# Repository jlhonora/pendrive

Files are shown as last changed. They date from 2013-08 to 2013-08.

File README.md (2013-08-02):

Build your own pendrive
=======================

This repo contains all the necessary material to build your own open-source pendrive, including the software source code, the design files and Gerber prints for the Printed Circuit Board and the 3D model of the plastic enclosure. Feel free to modify it as you like!

The microcontroller used is a TI msp430 of the F55xx family (msp430F5510 for now).

To use this library you need to [install mspgcc](https://github.com/jlhonora/mspgcc-install) and the __rake__ utility.

*WARNING*: The available code has only been tested on the [msp-exp430f5529](http://www.ti.com/tool/msp-exp430f5529) board. The PCB files are only an initial draft, and not a single one has been produced/tested.

## Motivation and principles ##

Technological devices that we use nowadays seem to be very far off from what someone could assemble at home. With this project we try to take down that myth, bringing technology and it's manufacturing process closer to normal people. 

The principles on which this project is built are the following:

- Open source code and designs
- Relatively easy soldering/assembly
- Expandable memory
- Small footprint/dimension

## Building the source code ##

First, build the source code:

    $ rake

And install it:

    $ sudo mspdebug rf2500 "prog bin.elf"

## References ##

The code here is heavily based on TI's msp-exp430F5529 User Experience Source Code, released under a BSD license.

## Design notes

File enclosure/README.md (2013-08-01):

Build your own pendrive - Enclosure design
==========================================

Since the PCB doesn't have a stable version, no enclosure has been designed yet.

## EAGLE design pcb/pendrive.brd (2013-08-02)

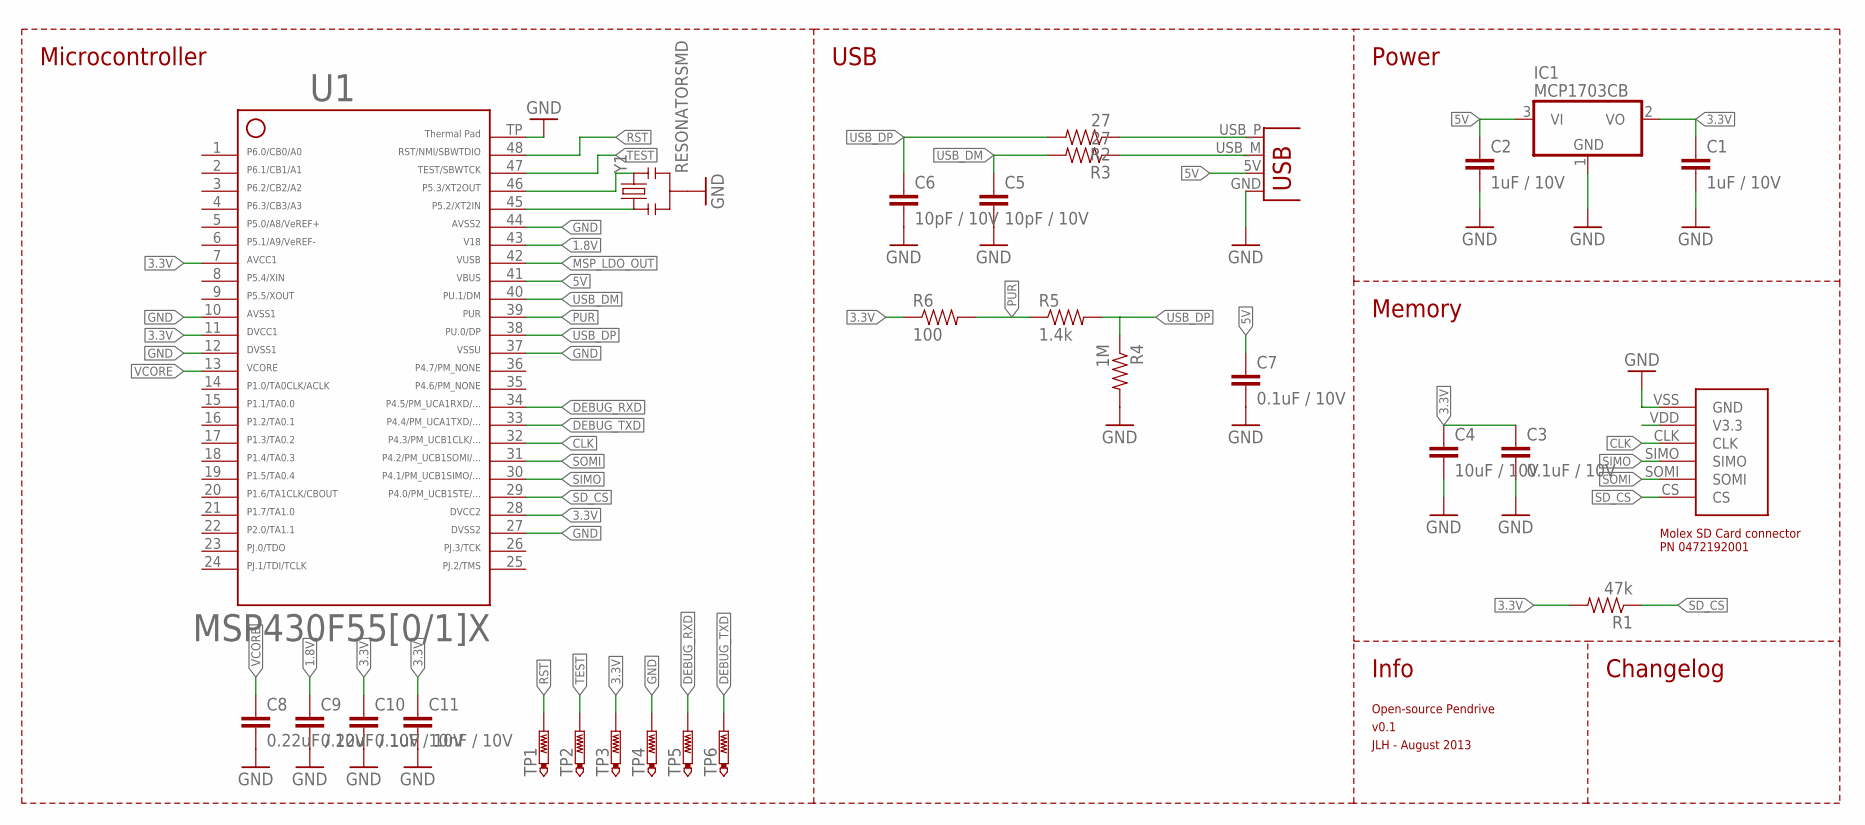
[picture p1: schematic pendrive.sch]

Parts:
C1, C2: 1uF / 10V; 0402-CAP
C3, C7, C10: 0.1uF / 10V; 0402-CAP
C4: 10uF / 10V; 1206
C5, C6: 10pF / 10V; 0402-CAP
C8, C9: 0.22uF / 10V; 0402-CAP
C11: 10nF / 10V; 0402-CAP
IC1: MCP1703CB; SOT23
R1: 47k; 0402-RES
R2, R3: 27; 0402-RES
R4: 1M; 0402-RES
R5: 1.4k; 0402-RES
R6: 100; 0402-RES
TP1, TP2, TP3, TP4, TP5, TP6: PTR1TP10SQ; TP10SQ
U1: F55[0/1]X---RGZ48; RGZ48
U2: MICROSD-MOLEX
X1: USBPCB; USB-A-PCB
Y1: RESONATORSMD; RESONATOR-SMD

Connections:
1.8V: C9.1, U1.43
3.3V: C1.1, C3.1, C4.1, C10.1, C11.1, IC1.2 (VO), R1.2, R6.1, TP3.TP, U1.7, U1.11, U1.28, U2.VDD (V3.3)
5V: C2.1, C7.1, IC1.3 (VI), U1.41, X1.5V (VBUS)
CLK: U1.32, U2.CLK
DEBUG_RXD: TP5.TP, U1.34
DEBUG_TXD: TP6.TP, U1.33
GND: C1.2, C2.2, C3.2, C4.2, C5.2, C6.2, C7.2, C8.2, C9.2, C10.2, C11.2, IC1.1 (GND), R4.2, TP4.TP, U1.10, U1.12, U1.27, U1.37, U1.44, U1.TP (49), U2.VSS (GND), X1.GND, Y1.2
MSP_LDO_OUT: U1.42
unnamed: R2.1, X1.USB_P (D+)
unnamed: R3.1, X1.USB_M (D-)
unnamed: U1.45, Y1.1
unnamed: U1.46, Y1.3
PUR: R5.1, R6.2, U1.39
RST: TP1.TP, U1.48
SD_CS: R1.1, U1.29, U2.CS
SIMO: U1.30, U2.SIMO
SOMI: U1.31, U2.SOMI
TEST: TP2.TP, U1.47
USB_DM: C5.1, R3.2, U1.40
USB_DP: C6.1, R2.2, R4.1, R5.2, U1.38
VCORE: C8.1, U1.13

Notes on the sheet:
Open-source Pendrive
v0.1
JLH - August 2013
Microcontroller
Power
Memory
Info
Changelog
USB
Molex SD Card connector PN 0472192001

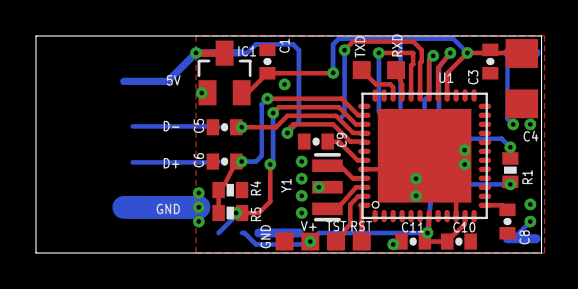
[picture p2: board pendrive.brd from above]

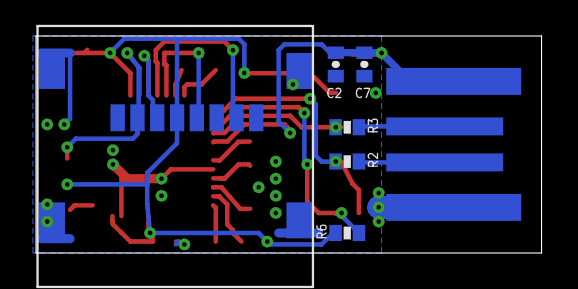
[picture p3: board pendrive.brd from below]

Board: 2 copper layers, 28.1 x 12.1 mm, 28 parts (7 on the bottom side), 20 nets.

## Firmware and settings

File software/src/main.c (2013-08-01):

/** 
 *  Build your own pendrive
 *  An open-source pendrive based on msp430
 *  microcontrollers.
 *
 *  To build the source code, just run:
 * 
 *  rake
 *
 *  To install it in the msp-exp430f5529 board:
 *  sudo mspdebug rf2500 "prog bin.elf"
 *
 *  This code was modified from the USB
 *  Developers Package available from the TI
 *  website. This code is provided as-is
 *  and comes with no warranty or support
 *  whatsoever. You are free to use it as long
 *  as you cite this work.
 *
 *  Enjoy!
 *
 *  Jose L. Honorato
 *  July, 2013
 */

#include <msp430.h>
#include <stdint.h>
#include "utils.h"

#define _MSC_

#ifdef _MSC_
#include "HAL_Board.h"
#include "F5xx_F6xx_Core_Lib/HAL_UCS.h"
#include "F5xx_F6xx_Core_Lib/HAL_PMM.h"
#include "MassStorage.h"
#endif

// Function declarations
void msp_init(void);
uint8_t events_available(void);
void process_events(void);

// To activate testing the rake command
// should be invoked like this:
// rake test=1
#ifdef TESTING
#include "test.h"
#endif

int main(void) {
    // If TESTING is defined at compile time then
    // we don't run the main application
    // This can be done by executing
    // rake test=1
#ifdef TESTING
    return test();
#endif
    // Initialize the different parts
    msp_init();

    DEBUG("Running\r\n");

    // Main loop
    while(1) {  
        // Check if there are events available. If there are
        // then we process them
        if(events_available()) {
            process_events();
        }
    }
}

/** Initializes modules and pins */
void msp_init(void) {
    // Stop the watchdog
    wdt_stop();
#ifdef _MSC_
    // Stop WDT
    WDTCTL = WDTPW + WDTHOLD;
    // Basic GPIO initialization
    Board_init();

    // Set Vcore to accomodate for max. allowed system speed
    SetVCore(3);

    // Use 32.768kHz XTAL as reference
    LFXT_Start(XT1DRIVE_0);

    // Set system clock to 12MHz
    Init_FLL_Settle(12000, 12000 / 32768);

    uart_a1_enable();
    uart_a1_change_baud(BAUD_RATE_19200);
    DEBUG("Testing Debug\r\n");

    SFRIFG1 = 0;

    // Globally enable interrupts
    __enable_interrupt();

    __delay_cycles(10000);
    DEBUG("Entering MassStorage\r\n")
    MassStorage();
#endif
    // Enable global interrupts
    __enable_interrupt();
    while(1);
}

/** Checks if there are events available to be processed
 * The currently supported events are:
 *   - none
 *
 *   These events are checked quite frequently because the main
 *   loop is constantly checking them. Anyhow, whenever we need to process
 *   a lengthy task, the main loop will cease to check for an event. 
 *   This doesn't mean that the events will be dropped, but they will 
 *   not be managed instantly.
 */
uint8_t events_available(void) {
    return (
        0
        );
}

/** Process then events queried in the \ref events_available() function */
void process_events(void) {
}

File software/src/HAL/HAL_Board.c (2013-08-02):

/*******************************************************************************
 *
 *  HAL_Board.c - General experimenter's board port initialization and control
 *
 *  Copyright (C) 2010 Texas Instruments Incorporated - http://www.ti.com/
 *
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
 *    Redistributions of source code must retain the above copyright
 *    notice, this list of conditions and the following disclaimer.
 *
 *    Redistributions in binary form must reproduce the above copyright
 *    notice, this list of conditions and the following disclaimer in the
 *    documentation and/or other materials provided with the
 *    distribution.
 *
 *    Neither the name of Texas Instruments Incorporated nor the names of
 *    its contributors may be used to endorse or promote products derived
 *    from this software without specific prior written permission.
 *
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
 ******************************************************************************/

/***************************************************************************//**
 * @file       HAL_Board.c
 * @addtogroup HAL_Board
 * @{
 ******************************************************************************/
#include <msp430.h>
#include "HAL_Board.h"

#define XT1_XT2_PORT_DIR            P5DIR
#define XT1_XT2_PORT_OUT            P5OUT
#define XT1_XT2_PORT_SEL            P5SEL
#define XT1_ENABLE                  (BIT4 | BIT5)
#define XT2_ENABLE                  (BIT2 | BIT3)
#define LED145678_PORT_OUT          P1OUT

/***************************************************************************//**
 * @brief  Initialize the board - configure ports
 * @param  None
 * @return none
 ******************************************************************************/

void Board_init(void)
{
    // Setup XT1 and XT2
    XT1_XT2_PORT_SEL |= XT1_ENABLE | XT2_ENABLE;
    P5SEL |= 0x0C;

    // Configure button ports
    PADIR &= ~0x0480;               // Buttons on P1.7/P2.2 are inputs

    // Configure SDCard ports
    P3OUT |= BIT7;                  // SD_CS to high
    P3DIR |= BIT7;

    // Configure unused ports for low power
    P2OUT &= ~(BIT0 + BIT1 + BIT3 + BIT4 + BIT6);
    P2DIR |= BIT0 + BIT1 + BIT3 + BIT4 + BIT6;

    P3OUT &= ~(BIT0 + BIT1 + BIT2);
    P3DIR |= BIT0 + BIT1 + BIT2;

    P4OUT &= ~(BIT0 + BIT6 + BIT7);
    P4DIR |= BIT0 + BIT6 + BIT7;

    P5OUT &= ~BIT1;
    P5DIR |= BIT1;

    P6OUT &= ~(BIT6 + BIT7);
    P6DIR |= BIT6 + BIT7;

    // LEDs
    P1SEL &= ~(BIT1 | BIT2 | BIT3 | BIT4 | BIT5);
    P1DIR |= (BIT1 | BIT2 | BIT3 | BIT4 | BIT5);
    P1OUT &= ~(BIT1 | BIT2 | BIT3 | BIT4 | BIT5);

    P4SEL |= BIT4 | BIT5; // UART
    P4MAP4 = PM_UCA1TXD;
    P4MAP5 = PM_UCA1RXD;
}

/***************************************************************************//**
 * @brief  Turn on LEDs
 * @param  ledMask   Use values defined in HAL_board.h for the LEDs to turn on
 * @return none
 ******************************************************************************/

void Board_ledOn(uint8_t ledMask)
{
    if (ledMask & LED1) LED145678_PORT_OUT |= BIT0;
    if (ledMask & LED4) LED145678_PORT_OUT |= BIT1;
    if (ledMask & LED5) LED145678_PORT_OUT |= BIT2;
    if (ledMask & LED6) LED145678_PORT_OUT |= BIT3;
    if (ledMask & LED7) LED145678_PORT_OUT |= BIT4;
    if (ledMask & LED8) LED145678_PORT_OUT |= BIT5;
}

/***************************************************************************//**
 * @brief  Turn off LEDs
 * @param  ledMask   Use values defined in HAL_board.h for the LEDs to turn off
 * @return none
 ******************************************************************************/

void Board_ledOff(uint8_t ledMask)
{
    if (ledMask & LED1) LED145678_PORT_OUT &= ~BIT0;
    if (ledMask & LED4) LED145678_PORT_OUT &= ~BIT1;
    if (ledMask & LED5) LED145678_PORT_OUT &= ~BIT2;
    if (ledMask & LED6) LED145678_PORT_OUT &= ~BIT3;
    if (ledMask & LED7) LED145678_PORT_OUT &= ~BIT4;
    if (ledMask & LED8) LED145678_PORT_OUT &= ~BIT5;
}

/***************************************************************************//**
 * @brief  Toggle LEDs
 * @param  ledMask   Use values defined in HAL_board.h for the LEDs to toggle
 * @return none
 ******************************************************************************/

void Board_ledToggle(uint8_t ledMask)
{
    if (ledMask & LED1) LED145678_PORT_OUT ^= BIT0;
    if (ledMask & LED4) LED145678_PORT_OUT ^= BIT1;
    if (ledMask & LED5) LED145678_PORT_OUT ^= BIT2;
    if (ledMask & LED6) LED145678_PORT_OUT ^= BIT3;
    if (ledMask & LED7) LED145678_PORT_OUT ^= BIT4;
    if (ledMask & LED8) LED145678_PORT_OUT ^= BIT5;
}

/***************************************************************************//**
 * @}
 ******************************************************************************/

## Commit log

2013-08-01 Added schematic, board not routed yet
    [pendrive.brd, pendrive.sch]
2013-08-01 First layout of components, not routed yet
    [pendrive.brd]
2013-08-02 Added first routed PCB version, not tested yet
    [pendrive.brd]
2013-08-02 Added programming and test points
    [pendrive.brd, pendrive.sch]
2013-08-02 Added small footprint as a goal
2013-08-02 Shrinked the board a little bit
    [pendrive.brd, pendrive.sch]
2013-08-02 Added labels to test points and components
    [pendrive.brd]
2013-08-02 Did a DRC, corrected a few things
    [pendrive.brd]
2013-08-02 Changed a couple of things towards 5510 compilation

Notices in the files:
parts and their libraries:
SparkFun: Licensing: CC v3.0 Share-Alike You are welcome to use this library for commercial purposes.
